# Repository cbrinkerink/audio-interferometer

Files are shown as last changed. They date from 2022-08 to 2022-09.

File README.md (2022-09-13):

# audio-interferometer
Using an FPGA to sample audio from multiple digital microphones and perform correlation, then visualise it on a PC. Presently, this repository is a hodgepodge of things including source files, executables, libraries and build scripts. I have tried to stay cross-platform, but everything so far only has been made to compile on OSX.

## Sources used
I have used OpenGL C++ code from the LearnOpenGL tutorial series (specifically, tutorial 4.1 from section 1). I got the serial connection stuff from a question on stackoverflow :)

The Ethernet core is from LiteEth, it is an independently synthesized core using the gen.py script in that codebase.

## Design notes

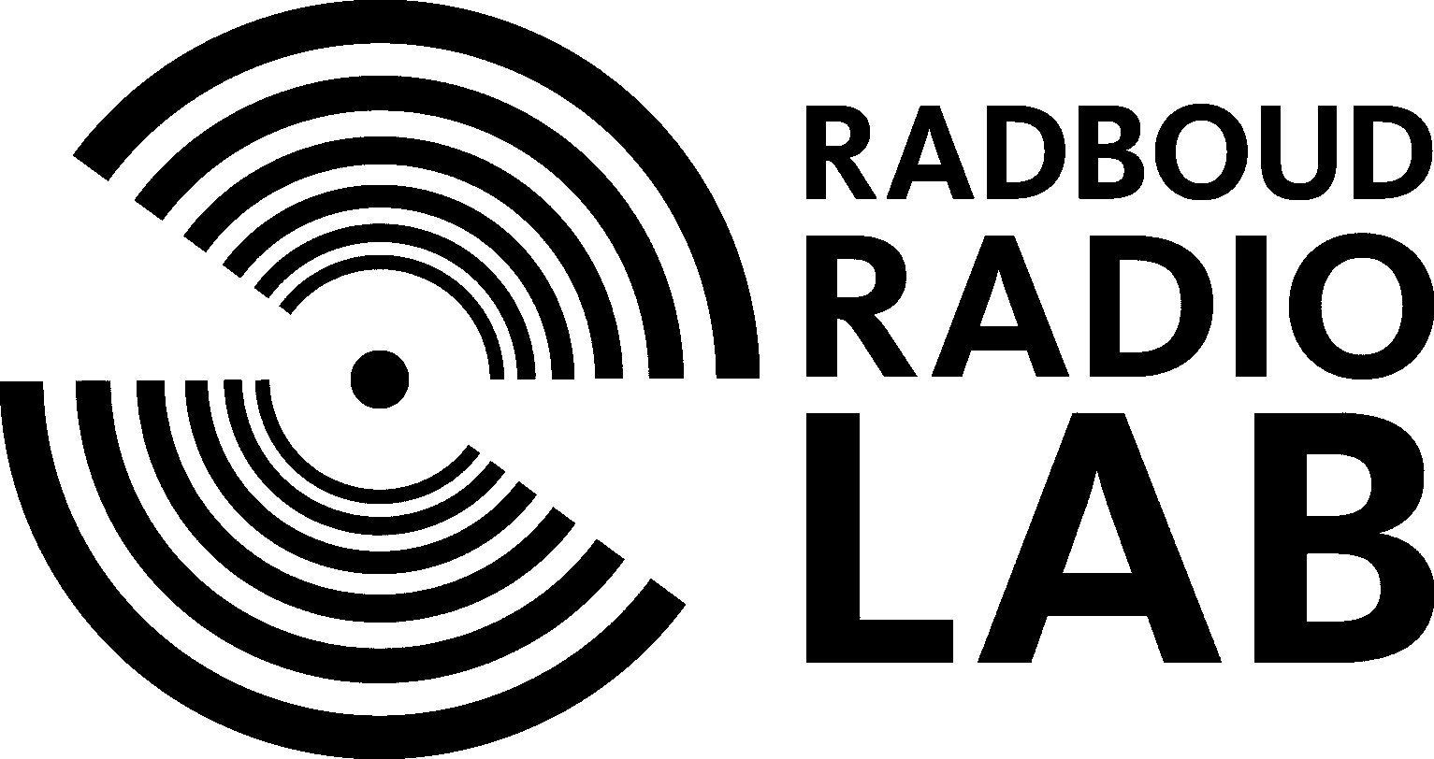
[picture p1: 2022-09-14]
power distribution board/v3/rrl_wb.png

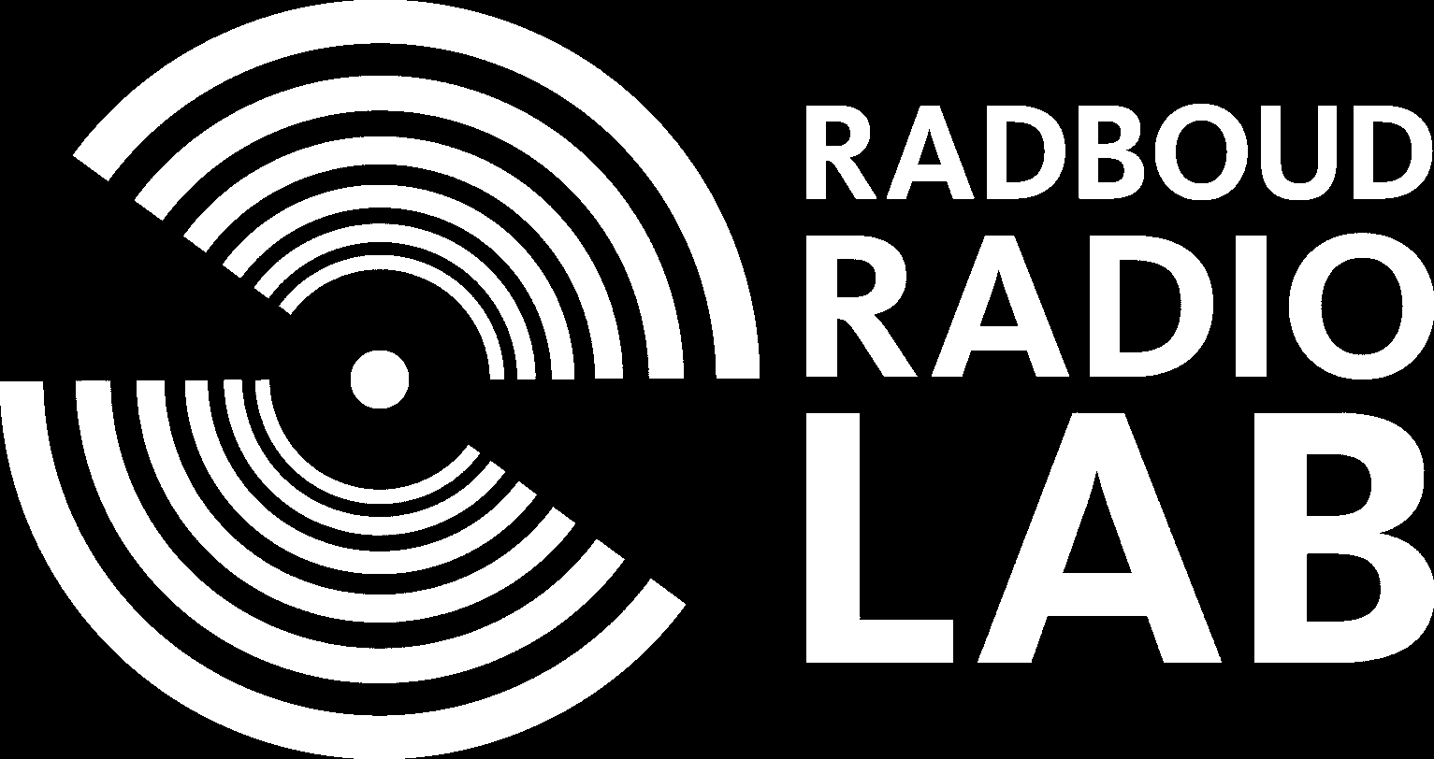
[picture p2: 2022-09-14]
power distribution board/v3/rrl_bw.png

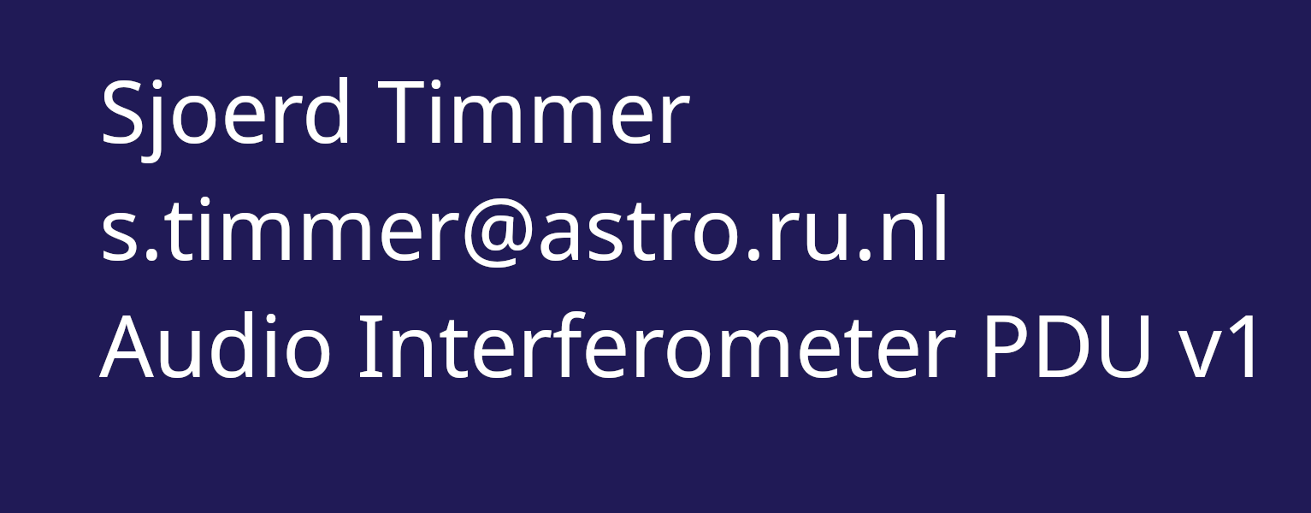
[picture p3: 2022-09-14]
power distribution board/v3/label.png

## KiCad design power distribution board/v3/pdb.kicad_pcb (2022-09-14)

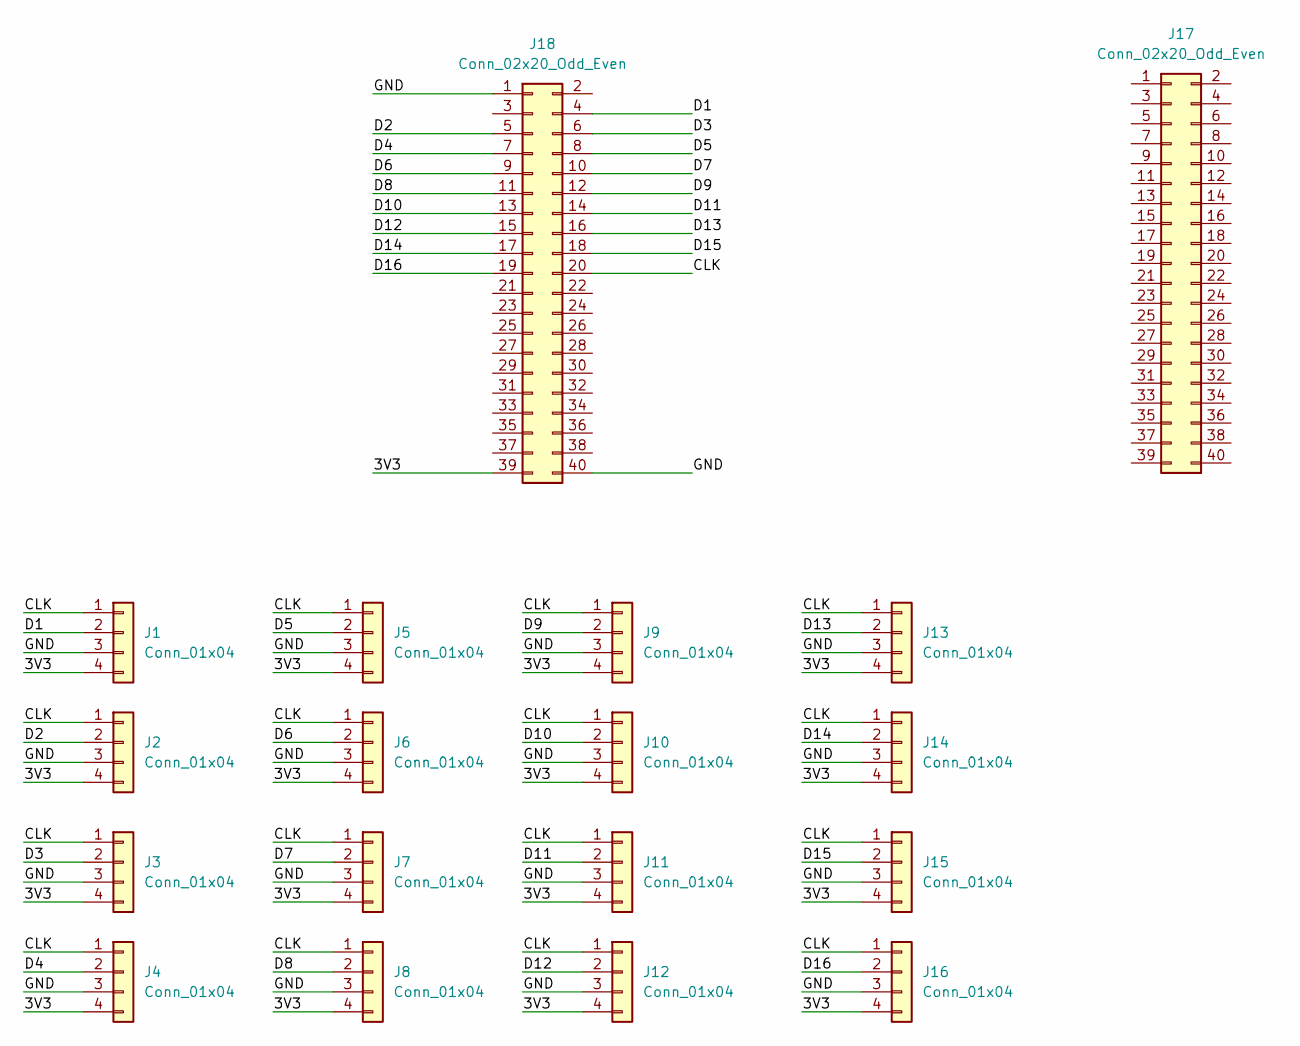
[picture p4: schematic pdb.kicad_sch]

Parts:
J1, J2, J3, J4, J5, J6, J7, J8, J9, J10, J11, J12, J13, J14, J15, J16: Conn_01x04; PinHeader_1x04_P2.54mm_Horizontal
J17, J18: Conn_02x20_Odd_Even; PinSocket_2x20_P2.54mm_Vertical

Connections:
/3V3: J1.4, J2.4, J3.4, J4.4, J5.4, J6.4, J7.4, J8.4, J9.4, J10.4, J11.4, J12.4, J13.4, J14.4, J15.4, J16.4, J18.39
/CLK: J1.1, J2.1, J3.1, J4.1, J5.1, J6.1, J7.1, J8.1, J9.1, J10.1, J11.1, J12.1, J13.1, J14.1, J15.1, J16.1, J18.20
/D1: J1.2, J18.4
/D2: J2.2, J18.5
/D3: J3.2, J18.6
/D4: J4.2, J18.7
/D5: J5.2, J18.8
/D6: J6.2, J18.9
/D7: J7.2, J18.10
/D8: J8.2, J18.11
/D9: J9.2, J18.12
/D10: J10.2, J18.13
/D11: J11.2, J18.14
/D12: J12.2, J18.15
/D13: J13.2, J18.16
/D14: J14.2, J18.17
/D15: J15.2, J18.18
/D16: J16.2, J18.19
/GND: J1.3, J2.3, J3.3, J4.3, J5.3, J6.3, J7.3, J8.3, J9.3, J10.3, J11.3, J12.3, J13.3, J14.3, J15.3, J16.3, J18.1, J18.40

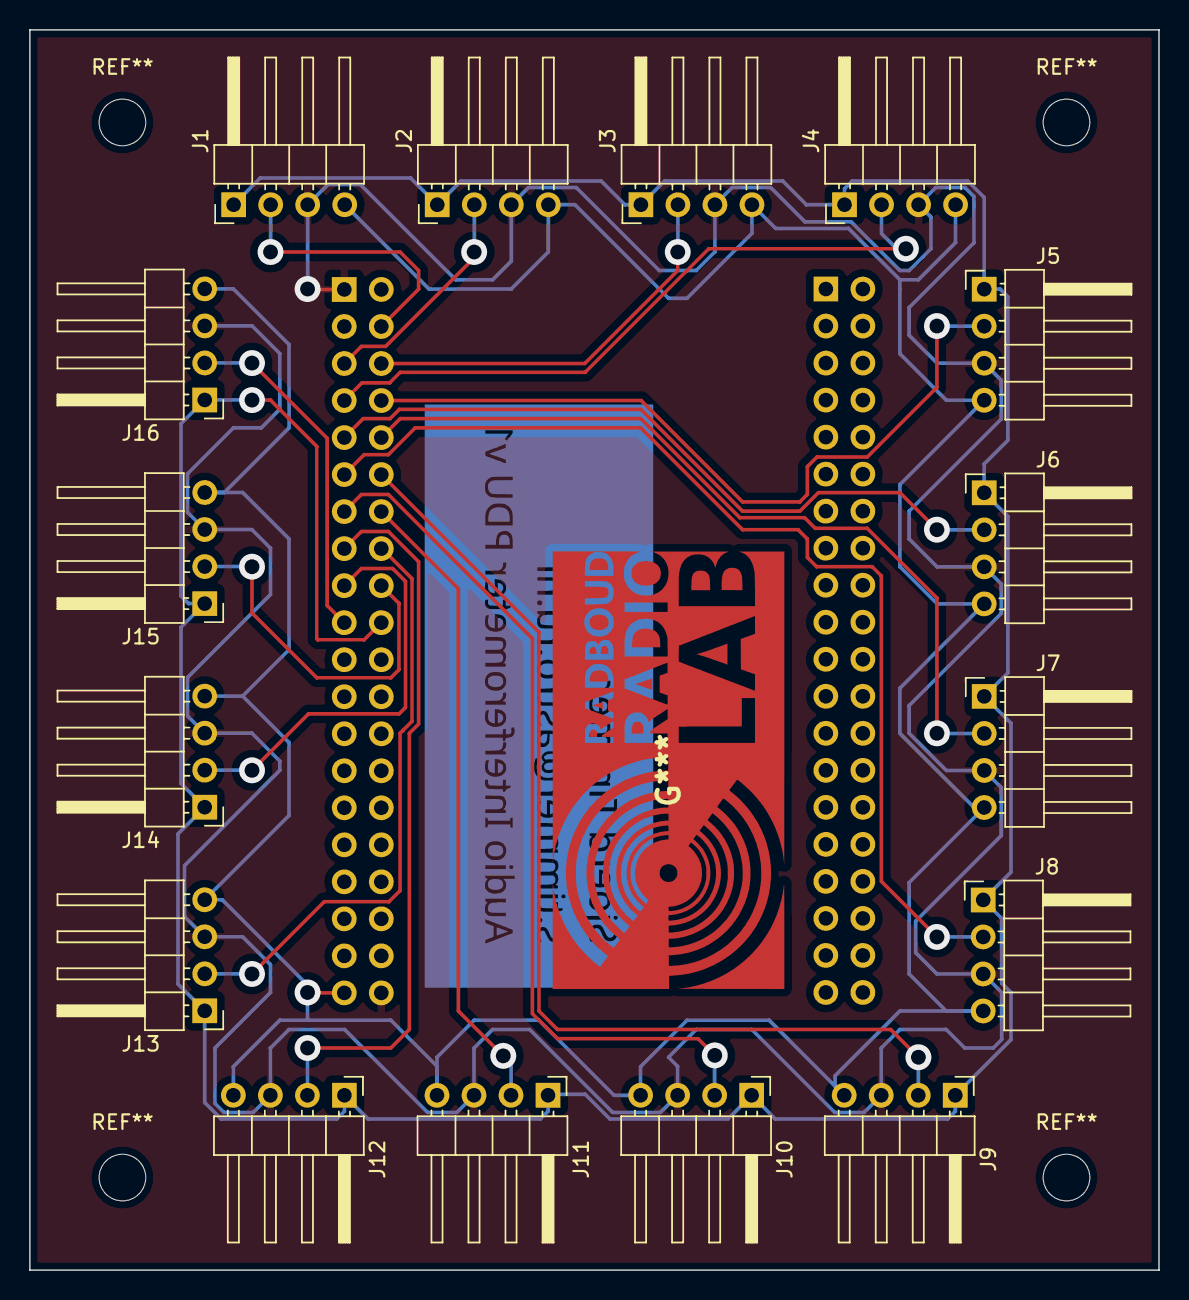
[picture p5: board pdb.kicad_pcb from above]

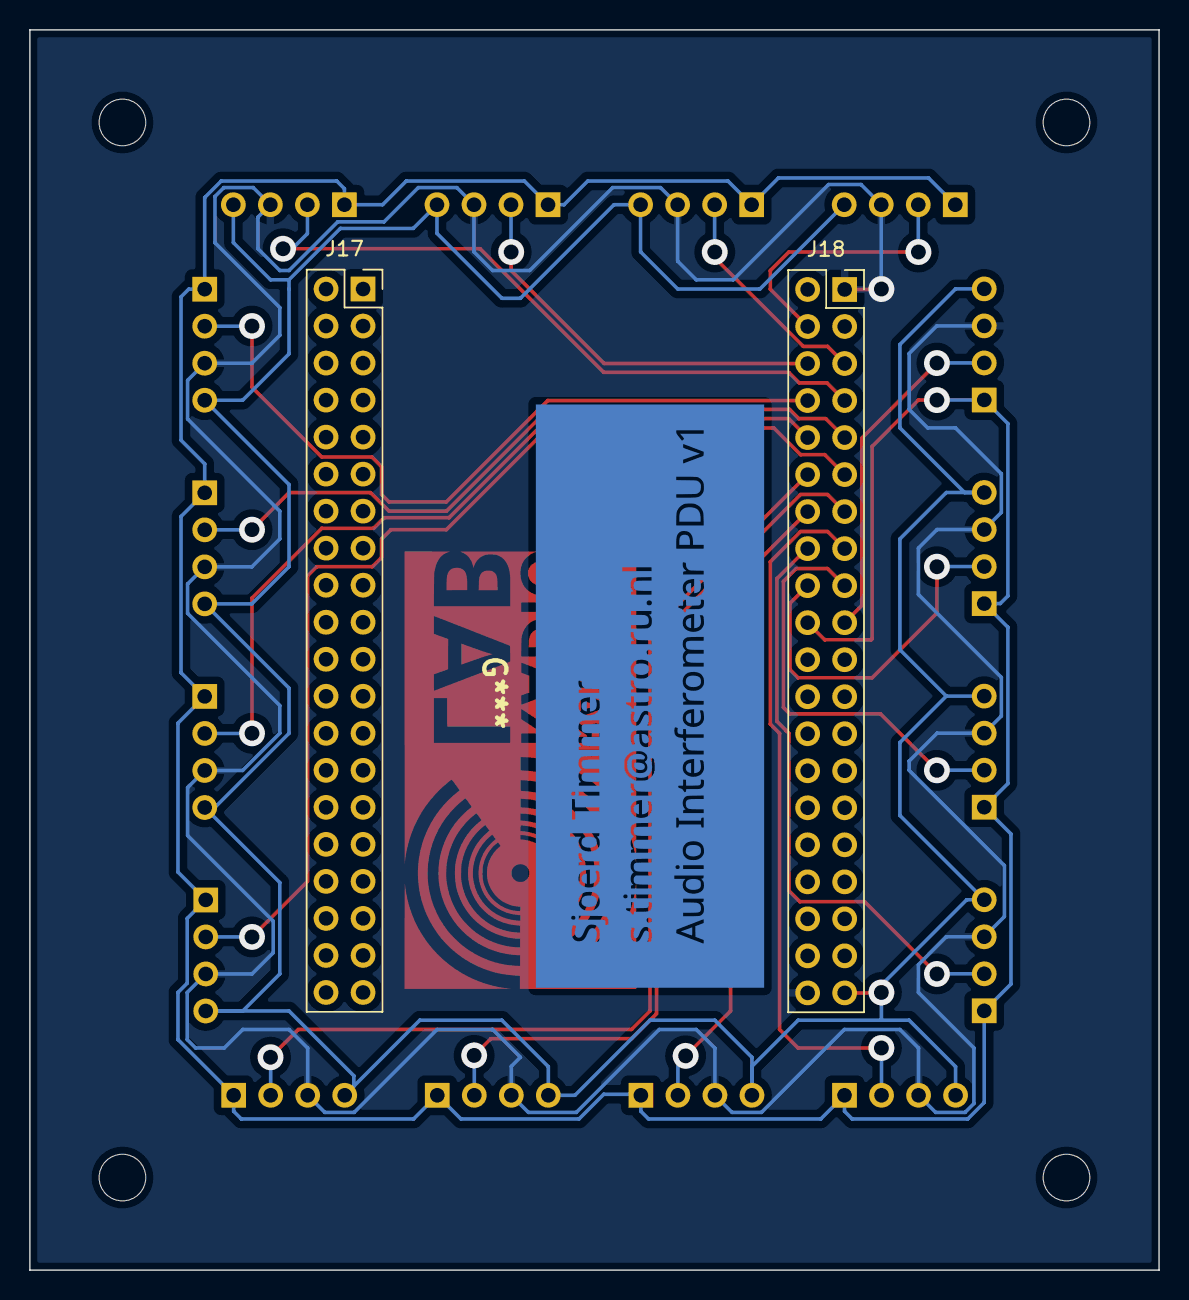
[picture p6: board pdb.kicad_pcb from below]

Board: 2 copper layers, 77.5 x 85.1 mm, 18 parts (2 on the bottom side), 19 nets.

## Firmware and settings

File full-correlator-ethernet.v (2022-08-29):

// This lag correlator builds upon the elementary correlator, which was used
// to test the functionality for 2 microphone inputs. As we now want to read
// out 8 microphones and use a larger number of lags, the performance will
// have to be upgraded considerably. We also need to add some form of data
// output.
// To change or add:
// - DONE: Increase clock speed from 12 MHz to 120 MHz. This gives us more time per
// audio sample (640 clock cycles instead of 64) to process all the
// correlations.
// - IN PROGRESS: Divide the tasks to be done over the clock cycles in a different way: we
// will want to shift one audio sample buffer at a time, then calculate all
// correlations of that microphone with the other 7. We will therefore get
// a particular structure which is repeated, and hopefully allows us to code
// it in some form of shorthand.
// - Note that each time we correlate one microphone with the other 7, we need
// to keep track of the even/odd lag bins we are updating. This pattern
// changes for every microphone input we process.
// - DONE: We will have to work out how to transmit all the accumulator buffer data
// once an integration period is complete. We should set aside dedicated
// registers that hold these values while the next integration is already
// underway. Then, a separate communications block can take care of
// transmission.
//
// With 56 multipliers on the ECP5, we need to structure our multiplications.
// As we will need to shift the audio samples in order (1 mic at a time),
// we will need to process all the lags from one newly shifted microphone
// before moving on to the next one. It is therefore convenient to have
// a suitable number of lag bins. Note that we need to process the even or odd
// lags at one time only, so we should work with half the lag bins.
// One sample is 7.3mm of traveled distance for sound, so 56 lags is 40.98 cm.
// We can start with 112 lags (81.96 cm), so that we can process half of those in one
// clock cycle.
// We will do all correlations of mic 1 with mics 2 thru 8, taking 7 clock
// cycles. Then the other 7 mics are up, taking 7 * 7 = 49 more clock cycles.
// All correlation is then done in 56 clock cycles.
//
// We will also need to take care of packetising the output lag buffer!
// Currently, it spits out all its contents in one long series of bits. We
// need to adopt this to use packets of 10 bits, with 1 start bit, 8 payload
// bits and 1 stop bit so that the serial interface can read it properly.

`timescale 1ns/1ns
`default_nettype none

module top (input wire clk_100MHz, // Change when using sim
	    //input wire clk_120MHz, // Change when using sim
	    //input wire clk_12MHz, // Change when using sim
	    input wire mic_data_1,
	    input wire mic_data_2,
	    input wire mic_data_3,
	    input wire mic_data_4,
	    input wire mic_data_5,
	    input wire mic_data_6,
            output wire uart_tx,
	    output wire mic_clk_1,
	    output wire mic_clk_2,
	    output wire mic_clk_3,
	    output wire mic_clk_4,
	    output wire mic_clk_5,
	    output wire mic_clk_6,
	    output wire split_out_1,
	    output wire split_out_2,
	    output wire split_out_3,
            output wire LED_1,
            output wire LED_2,
            output wire LED_3,
            output wire LED_4,
            // Inputs
            input i_versa_rst_n, // reset
            input clk_125MHz, // PHY output clock, CDB added for debugging
            // liteeth inputs (output of PHY)
            input i_liteeth_rgmii_eth_clocks_rx,
            input i_liteeth_rgmii_eth_rx_ctl,
            input [3:0] i_liteeth_rgmii_eth_rx_data,
            // liteeth outputs (input for PHY)
            output o_liteeth_rgmii_eth_clocks_tx,
            output o_liteeth_rgmii_eth_tx_ctl,
            output [3:0] o_liteeth_rgmii_eth_tx_data,
            output o_liteeth_rgmii_eth_rst_n,
	    // PHY management 
            output o_liteeth_rgmii_eth_mdc,
            inout i_liteeth_rgmii_eth_mdio
    );

parameter NUMLAGS = 128;

// LiteEth connections for sending data
wire liteeth_udp_tx_valid;
wire liteeth_udp_tx_last;
wire [31:0] liteeth_udp_tx_data;

wire liteeth_udp_tx_ready;

// LiteEth clock wires
wire i_liteeth_rgmii_eth_clocks_rx;
wire o_liteeth_rgmii_eth_clocks_tx;

// Unused LiteEth connections
wire liteeth_udp_rx_valid;
wire liteeth_udp_rx_last;
wire liteeth_udp_rx_ready;
wire [31:0] liteeth_udp_rx_data;
wire liteeth_udp_rx_error;

wire [17:0] CIC_to_correlator_1;
wire [17:0] CIC_to_correlator_2;
wire [17:0] CIC_to_correlator_3;
wire [17:0] CIC_to_correlator_4;
wire [17:0] CIC_to_correlator_5;
wire [17:0] CIC_to_correlator_6;

wire [17:0] d_test_1;
wire [17:0] d_test_2;
wire [17:0] d_test_3;
wire [17:0] d_test_4;
wire [17:0] d_test_5;
wire [17:0] d_test_6;
wire [17:0] d_test_7;
wire [17:0] d_test_8;
wire [17:0] d_test_9;
wire [17:0] d_test_10;
wire [17:0] d_test_11;
wire [17:0] d_test_12;

wire load_data_1;
wire locked;

(* keep="soft" *)
wire load_data_2;
wire load_data_3;
wire load_data_4;
wire load_data_5;
wire load_data_6;

wire data_out;

// --- Comment out if using sim ---
wire clk_12MHz;
wire clk_120MHz;

//-- PDM clock
wire clk_3MHz;

reg [27:0] long_counter = 0;

wire [31:0] lag_data_12;
wire [31:0] lag_data_23;
wire [31:0] lag_data_31;
wire [31:0] lag_data_14;
wire [31:0] lag_data_24;
wire [31:0] lag_data_34;
wire [31:0] lag_data_15;
wire [31:0] lag_data_25;
wire [31:0] lag_data_35;
wire [31:0] lag_data_45;
wire [31:0] lag_data_16;
wire [31:0] lag_data_26;
wire [31:0] lag_data_36;
wire [31:0] lag_data_46;
wire [31:0] lag_data_56;
wire export_flag_12;
wire export_flag_23;
wire export_flag_31;
wire export_flag_14;
wire export_flag_24;
wire export_flag_34;
wire export_flag_15;
wire export_flag_25;
wire export_flag_35;
wire export_flag_45;
wire export_flag_16;
wire export_flag_26;
wire export_flag_36;
wire export_flag_46;
wire export_flag_56;
wire serial_data;

reg LED_1_state = 0;
reg LED_2_state = 0;
reg LED_3_state = 0;
reg LED_4_state = 0;

//always @ (posedge clk_100MHz) begin
//  long_counter = long_counter + 1;
//  if (long_counter[24] == 1) LED_1_state = ~ LED_1_state;
//  if (long_counter[23] == 1) LED_2_state = ~ LED_2_state;
//  if (long_counter[22] == 1) LED_3_state = ~ LED_3_state;
//  if (long_counter[21] == 1) LED_4_state = ~ LED_4_state;
//end

assign LED_1 = LED_1_state;
assign LED_2 = LED_2_state;
assign LED_3 = LED_3_state;
assign LED_4 = LED_4_state;

assign mic_clk_1 = clk_3MHz;
assign mic_clk_2 = clk_3MHz;
assign mic_clk_3 = clk_3MHz;
assign mic_clk_4 = clk_3MHz;
assign mic_clk_5 = clk_3MHz;
assign mic_clk_6 = clk_3MHz;

assign uart_tx = serial_data;
assign split_out_1 = mic_data_1;
assign split_out_2 = mic_data_2;
assign split_out_3 = mic_data_3;

// Change when using sim
pll_100_12 PLL_SLOW (.clk_100(clk_100MHz), .clk_12(clk_12MHz));

// 6 microphones
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

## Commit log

2022-07-28 Added display modes (T/P), calibrated lags by eye using a noise source
2022-09-13 Add preliminary version of power distribution board.
    [pdb.kicad_pcb, pdb.kicad_sch]
2022-09-14 More versions of power distribution board.
    [pdb.kicad_pcb, pdb.kicad_sch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]
2022-09-14 Tweaks to the layout.
    [pdb.kicad_pcb]
2022-10-05 Updated compile script for JSON use, fragment shader, pin mapping
2022-10-06 Updated verilog code to work with Sjoerd's header board
